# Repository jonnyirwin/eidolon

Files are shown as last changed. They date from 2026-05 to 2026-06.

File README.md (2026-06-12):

> ⚠️ **Work in progress — do not build this yet.** The PCB, case, and firmware have not been validated against a physical build. Things will change, things may be wrong. Watch the commits if you want to follow along, but don't order boards from these files yet.

# Eidolon

> **eidolon** /aɪˈdoʊlɒn/ *noun*
> An idealized image; a phantom or spectre of a person or thing.
> — from Greek εἴδωλον *(image, idol, phantom)*

---

A small column-staggered wireless split keyboard. 30 keys (5×3 + 2 thumb per half), Kailh Choc v1 switches, Seeed XIAO nRF52840 BLE, Totem-style clamshell case. Both halves are independent wireless units — no TRRS cable.

## Built on the shoulders of

| Keyboard | Role in this project |
|---|---|
| [**Phantom**](https://github.com/davidphilipbarr/Phantom) by davidphilipbarr | PCB layout source — key positions reverse-engineered from `lephantom.kicad_pcb`; board outline traced from the original `Edge.Cuts`. Eidolon matches the original key centres to < 0.15 mm. |
| [**TOTEM**](https://github.com/GEIGEIGEIST/TOTEM) by GEIGEIGEIST | Case design reference — switch hole dimensions, keycap recess depth, clamshell geometry, and hot-swap socket pocket profiles all taken from the Totem STEP file. |
| [**Rufous**](https://github.com/jcmkk3/trochilidae/) by jcmkk3 | XIAO BLE footprint and diode placement — `pcb/footprints/xiao_pogo.js` is adapted from the Rufous design; diodes in the Choc south LED cutout follow the same approach. |

## PCB

| Left half | Right half |
|---|---|
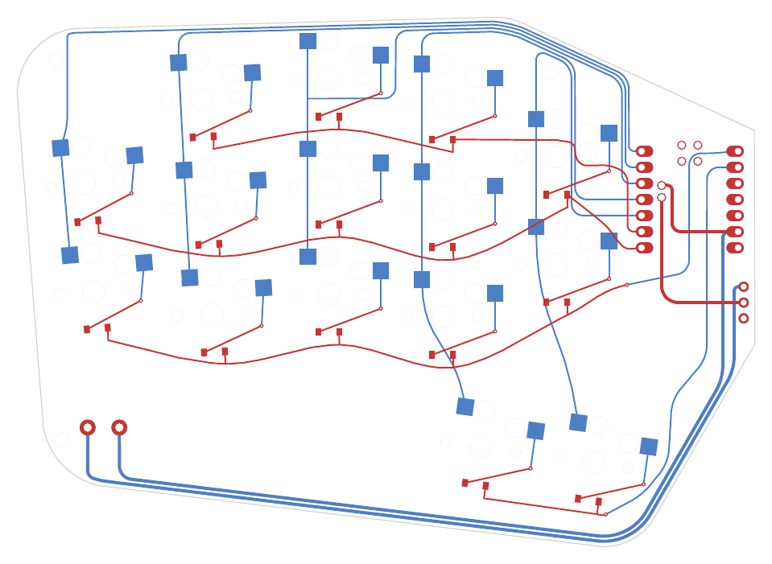
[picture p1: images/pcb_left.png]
Left PCB
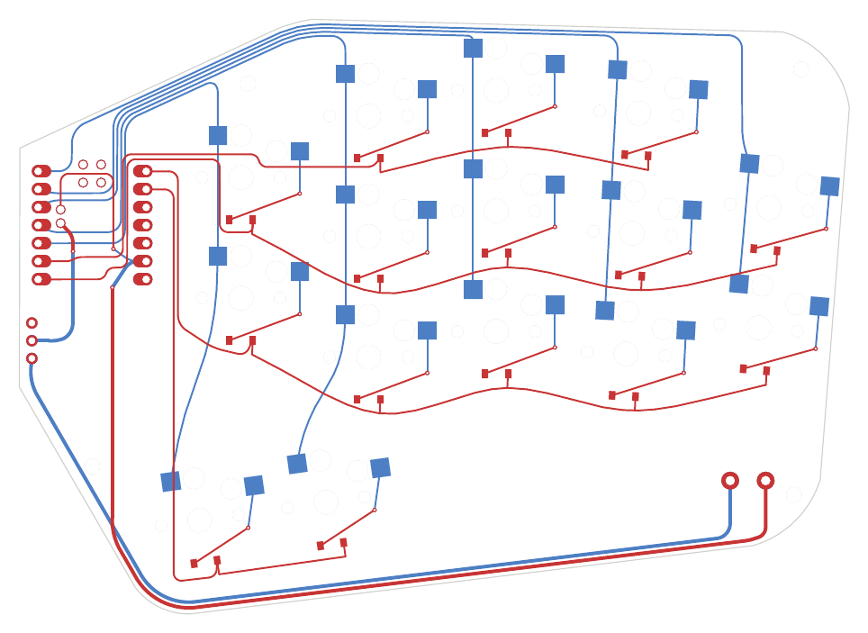
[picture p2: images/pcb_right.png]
Right PCB
|  |  |

## Case

| Top — left | Top — right |
|---|---|
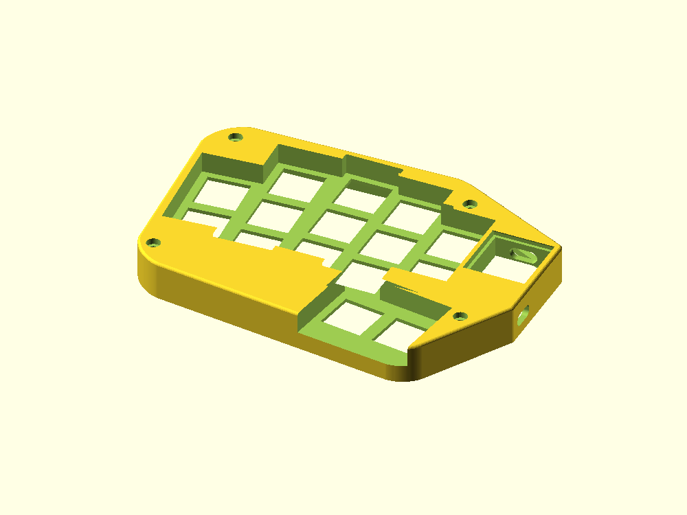
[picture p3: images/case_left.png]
Case top left
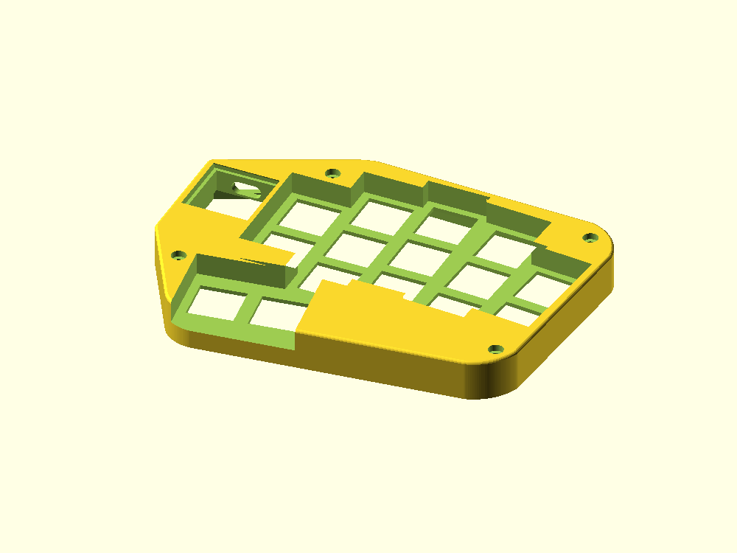
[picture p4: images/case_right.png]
Case top right
|  |  |

| Bottom — left | Bottom — right |
|---|---|
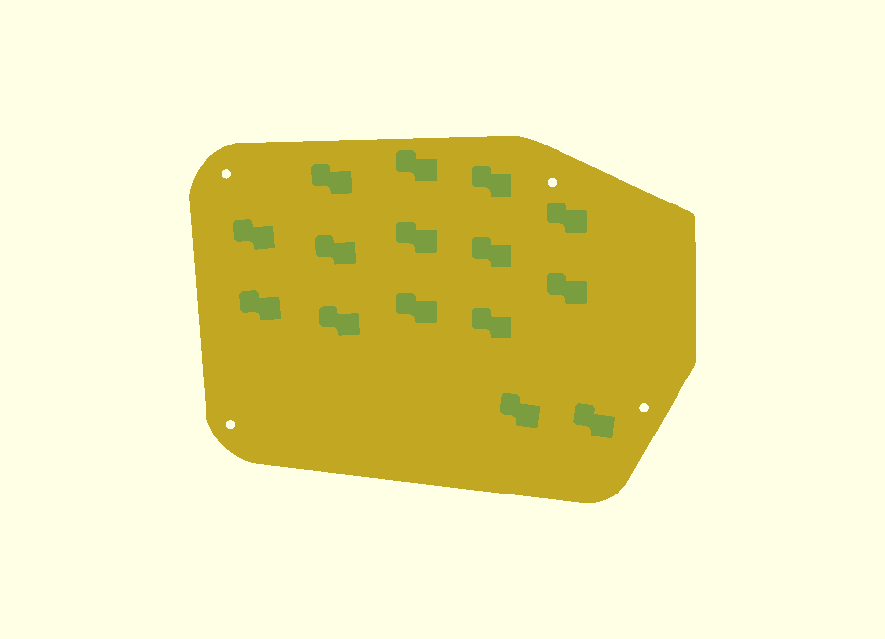
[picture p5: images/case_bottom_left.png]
Case bottom left
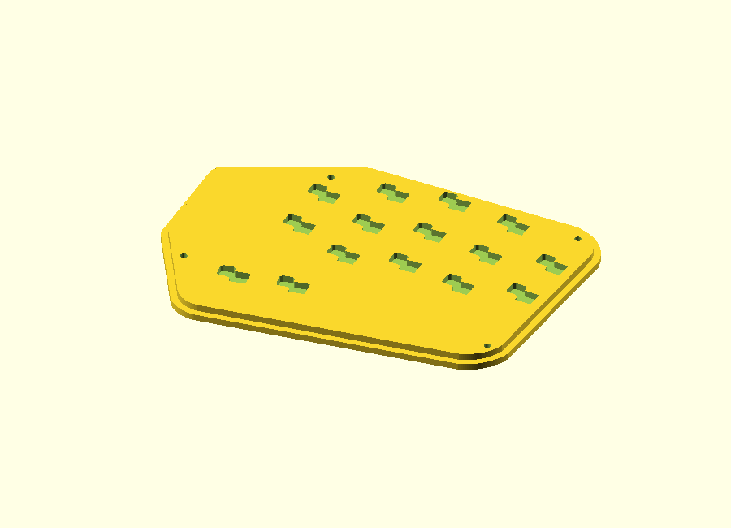
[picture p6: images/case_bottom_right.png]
Case bottom right
|  |  |

---

## Repository layout

```
pcb/              Ergogen source + routed KiCad files + gerbers
  eidolon.yaml      Ergogen config (geometry + nets)
  footprints/       custom Ergogen footprints
  build.js          local build wrapper (injects footprints)
  eidolon_left.kicad_pcb   routed left half
  eidolon_right.kicad_pcb  routed right half
  eidolon_left_gerbers.zip
  eidolon_right_gerbers.zip

case/             OpenSCAD case design
  eidolon_case.scad        top shell (both halves via -D right=true)
  eidolon_case_bottom.scad bottom shell
  stl/                     pre-generated STL files
```

---

## PCB build (Ergogen)

Custom footprints live in `pcb/footprints/`, so use the wrapper rather than the ergogen CLI directly:

```sh
cd pcb
npm install       # once
node build.js     # -> pcb/output/
```

Outputs land in `pcb/output/`:
- `outlines/board_left.svg|dxf`, `board_right.svg|dxf` — board perimeters
- `pcbs/eidolon_left.kicad_pcb`, `eidolon_right.kicad_pcb` — both halves, footprints + nets placed (no routes)

On **ergogen.xyz**, paste each file in `pcb/footprints/` into the web app's Footprints section under its filename (e.g. `reset_button`); `eidolon.yaml` then works as-is.

### Layout

```
 pinky  ring  middle index inner
   ·    top    top   top   ·       (pinky has no top row; inner has no bottom)
 home  home   home  home  upper
 bot   bot    bot   bot   lower
                  thumbL thumbR    (-8°)
```

Pinky splayed 5°, ring splayed 3°; other columns straight. Choc spacing: 18 mm columns, 17 mm rows.

### Wiring — COL2ROW diode matrix (XIAO BLE)

Each half is a fully independent wireless unit (own XIAO + battery, no TRRS).

| Matrix | Net | XIAO pin |
|---|-----|---|
| pinky col | C0 | D0 |
| ring col | C1 | D1 |
| middle col  | C2 | D2 |
| index col | C3 | D3 |
| inner col | C4 | D4 |
| top row | R0 | D5 |
| home row | R1 | D6 |
| bottom row  | R2 | D7 |
| thumb row | R3 | D8 |

Power: battery + → `RAW_BATT` → slide switch → `BATT` → XIAO `B+`; battery − → GND.

> **Verify before fab:** the XIAO pad→pin mapping in `pcb/footprints/xiao_pogo.js` assumes the standard castellation mounted face-down; confirm against the XIAO datasheet.

### Mirrored halves, not reversible

The original Phantom is a single reversible PCB flipped for both hands. Eidolon generates a true left and right board. Functionally identical, but the QMK firmware's `split.matrix_pins.right.direct` should *mirror* the left, not reverse it.

---

## Case (OpenSCAD)

`case/eidolon_case.scad` is the top shell for both halves. The right half is the left mirrored (`-D right=true`).

```sh
openscad -o case/stl/eidolon_case_top_left.stl  case/eidolon_case.scad
openscad -D right=true -o case/stl/eidolon_case_top_right.stl  case/eidolon_case.scad
openscad -o case/stl/eidolon_case_bottom_left.stl  case/eidolon_case_bottom.scad
openscad -D right=true -o case/stl/eidolon_case_bottom_right.stl  case/eidolon_case_bottom.scad
```

Pre-generated STLs are in `case/stl/`.

Top shell features: keycap recess field, stepped 13.8 mm Choc plate holes, XIAO pocket with acrylic window rebate + USB-C cutout, battery pocket, power-switch wall slot, M2 bolt pockets.

### Bottom shell

`case/eidolon_case_bottom.scad` nests inside the top from below. Geometry:

- z ∈ [−0.9, 0]: exterior plate matching the top case outer footprint
- z ∈ [0, 2.1]: nesting lip; PCB rests on the lip top at z = 2.1
- Per-switch hot-swap socket pockets (16 × 7 × 1 mm) cut into the lip top
- M2 hex nut pockets (4.0 mm AF × 1.8 mm) at the four bolt positions

### Mounting hardware

| Part | Spec | Count |
|---|---|---|
| Socket cap bolt | M2 × 12 mm | 4 per half |
| Hex nut | M2 (4.0 mm AF) | 4 per half |

### MCU acrylic window

Cut a piece of 1.5 mm clear acrylic to drop into the XIAO rebate:

| Dimension | Size |
|---|---|
| Width | 20.3 mm |
| Length | 22.8 mm |
| Thickness | 1.5 mm |

Angle the acrylic, slip the +y edge under the square lip (lip A), press the −y edge down past the chamfered lip (lip B). Remove the bottom shell to access the MCU.

---

## Firmware

ZMK firmware for the Eidolon is available at [jonnyirwin/zmk-keyboard-eidolon](https://github.com/jonnyirwin/zmk-keyboard-eidolon).

---

## Deviations from the original Phantom

- **Mirrored L/R** instead of a single reversible board.
- **BLE only** — XIAO nRF52840, COL2ROW diode matrix, battery + slide switch; Pro Micro and TRRS removed.
- **Diodes top-side**, in each Choc south LED gap — hotswap sockets are the only underside component.
- **Trackball omitted.**
- Board outline is the original `Edge.Cuts` polygon with 1.5 mm corner fillets.

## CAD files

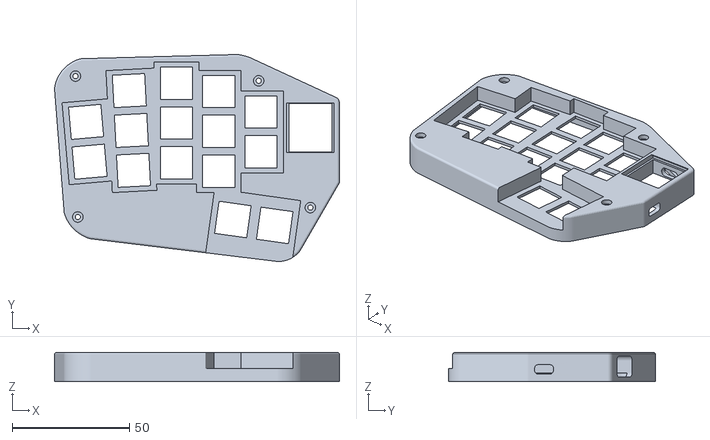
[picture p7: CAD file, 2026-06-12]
case/stl/eidolon_case_top_left.stl
121.3 x 88.1 x 12.5

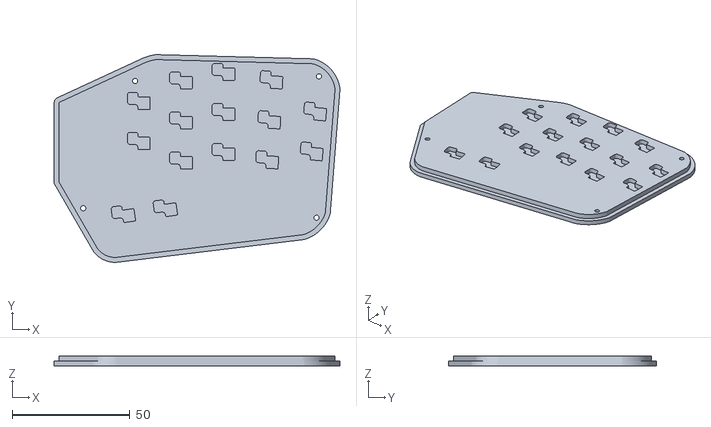
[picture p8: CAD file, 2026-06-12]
case/stl/eidolon_case_bottom_right.stl
121.4 x 88.2 x 4.10

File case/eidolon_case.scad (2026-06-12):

// Eidolon case — BOTH halves (left geometry; right = mirrored build).
// Outline from the PCB Edge.Cuts of lephantom.kicad_pcb (6 lines + 5 arcs,
// exact mm coordinates) plus the two routing reliefs now carried by BOTH
// ergogen PCBs (P1/P2 top edge -0.3mm, P10/P11 pinky edge -0.7mm), so the two
// boards are exact mirror images and one case design fits both. The case
// footprint is the PCB outline grown outward by (gap + wall) so the PCB drops
// inside the walls:
//   gap  = 0.15mm clearance between PCB edge and inner wall
//   wall = 2.0mm  case wall thickness
// then extruded. This pass produces the solid outer shape only.
//
//   openscad -o eidolon_case_top_left.stl  case/eidolon_case.scad
//   openscad -D right=true -o eidolon_case_top_right.stl case/eidolon_case.scad
//
// Right-half fit (verified against the routed ergogen boards): every
// footprint origin mirrors exactly (x_left + x_right = 170, same y), and the
// four case bolts ARE the PCB mounting holes. The XIAO keeps its orientation
// under the PCB mirror, but its position mirrors and the pocket/USB cutout
// are symmetric about the pocket axis, so the mirrored case still fits; the
// power switch flips orientation but its body centre and actuator height are
// unchanged, so the mirrored wall slot lines up.
right = false;   // build the right-half case (mirror of the left)

gap    = 0.15;   // PCB-to-inner-wall clearance (per side)
wall   = 2.0;    // case wall thickness
height = 12.5;   // extrusion depth (mm) — matches Totem top shell
switch = 13.8;   // Choc switch plate cutout (mm square) — Kailh spec / Totem STEP
// Per-column keycap recess. Depth/corner from Totem STEP; opening sized to the
// keycap (not the switch) so caps drop in without catching. At 18mm column pitch
// an 18mm cap leaves no rib, so adjacent column recesses merge into field pockets
// (as on the Totem, whose real recesses are big multi-column pockets).
recess_d = 6.85; // recess depth from top (rim->switch-plate in Totem)
keycap_x = 18.0; // keycap footprint, horizontal
keycap_y = 17.0; // keycap footprint, vertical
key_clr  = 0.5;  // extra clearance per side so caps don't catch
recess_r = 0;  // recess corner fillet
// Widen the recess on the RIGHT of the two leftmost columns (pinky+ring) by
// widen_f, extending them toward the next column to close the inter-column ribs.
// Top switches of the pinky+ring columns (the ones bordering the ribs); the
// bottom switch of each column (9, 11) is left at normal width.
widen_keys = [4, 1, 6];        // pinky-top, ring-top, ring-middle
widen_f    = 0.25;             // +25% width, added entirely on the right
// Stepped switch hole + plate (Totem STEP): below the recess floor sits a thin
// plate carrying the switch. The hole is 13.8mm for plate_t13 then opens to a
// 16mm counterbore for plate_t16; below the plate is a cavity for the PCB.
plate_t13 = 1.2;   // 13.8mm hole depth (upper, switch clips here)
plate_t16 = 0.75;  // 16mm counterbore depth (lower)
cbore     = 16.0;  // counterbore size
// derived z-levels (z=0 bottom, z=height top) — defined here so usb_z0 can use them
plate_top = height - recess_d;                 // recess floor / plate top (5.65)
plate_bot = plate_top - plate_t13 - plate_t16; // plate underside (3.70)
// XIAO BLE microcontroller — walled pocket on the right, a hole straight through
// the case (separate from the keycap recess). At the top (-y) end the slanted
// outer wall is flattened by a rounded-rectangular recess, and the USB-C socket
// cutout pierces that flat into the pocket. The PCB right edge is grown by
// pcb_pad (see outline) so the pocket has board under it + real walls.
xiao_l   = 20.0;            // board length (long axis, vertical / y)
xiao_w   = 17.5;           // board width (x)
xiao_clr = 0.4;            // clearance per side inside the pocket
xiao_pos = [137.0, 44.0];  // pocket center, KiCad coords — up near the top angle
xiao_rot = 0;              // deg; 0 = level with the right edge
// USB-C side: a rounded-rect recess cut into the top-right wall makes a flat
// face usb_wall in front of the pocket; the socket cutout goes through it.
flat_w   = 14.0;           // flat recess width  (x)
flat_h   = 9.0;            // flat recess height (z)
flat_r   = 2.0;            // flat recess corner radius
usb_wall = 2.0;            // wall left between the flat face and the pocket
usb_w    = 9.0;            // USB-C cutout width
usb_h    = 4.0;            // USB-C cutout height (3.2 socket + 0.8 clearance)
// SMD-mounted XIAO (castellated on PCB top): XIAO board sits on plate_bot with
// its own 1.0mm thickness, then the USB-C connector body extends ~3.16mm above
// that. Connector top is at plate_bot + 1.0 + 3.16 = plate_bot + 4.16. Place
// the cutout bottom 0.3mm below the XIAO PCB top to clear the connector body.
usb_z0   = plate_bot + 0.7;
// Acrylic cover over the XIAO through-hole: shallow rebate in the top deck,
// acrylic drops in flush with the deck top and rests on a ledge round the
// pocket. With SMD mount there's no MCU bump, so the rebate sits in the deck.
acrylic_t     = 1.5;       // acrylic thickness
acrylic_ledge = 1.0;       // ledge each side (rebate footprint > pocket footprint)
// Retention lips: deck material above the acrylic on the +/-y short ends that
// overhangs by lip_overhang, capturing the acrylic. One-time install: angle
// the acrylic to slip one short edge under one lip, then bow the acrylic
// slightly to push the other short edge past the second lip.
lip_t       = 0.6;        // lip vertical thickness (~3 print layers at 0.2mm)
lip_overhang= 0.8;        // lip A inward projection (full flat); lip B same width
                          // but flat for lip_b_flat with the rest chamfered.
lip_b_flat  = 0.4;        // lip B's flat retention width at the inner end
                          // (lip_overhang - lip_b_flat = chamfer width)
// Battery pocket — 301230 LiPo cell (3.0 x 12 x 30 mm) sits ON TOP of the PCB
// in the empty palm-rest area, hidden between the PCB and the underside of the
// deck. Pocket is cut UPWARD from plate_bot through the plate into the deck so
// the cell drops in from below before the PCB is seated; wires bend up to F.Cu
// pads on the PCB top (5mm apart, see footprints/battery.js). Bottom of the
// pocket is open to the under-PCB cavity (which the bottom shell will close).
bat_pos    = [59.625, 80.0]; // KiCad — palm-rest area, clear of every keycap pad
bat_rot    = 0;              // long axis along x (-90 = along y)
bat_x      = 38.75;          // pocket: 301230 cell (30) + 0.5 at +x + 8.25 wire
                             // well at -x. The well must hold the pad pair's
                             // 8.5mm copper span (TOTEM 5mm pitch, 2.5mm pads):
                             // moving the pads instead doesn't work — east puts
                             // pad-2 solder under the cell (0.25 margin), west
                             // pokes pad 1 out the wall. -x wall at 40.25 keeps
                             // 0.5 to pad-1 copper and 1.15 to the BL bolt shaft
bat_y      = 14.0;           // pocket width (cell 12 + 1mm each side)
bat_depth  = 3.5;            // cell + 0.5 clearance above plate_bot
// MSK-12D19 power switch — through-hole SPDT on the PCB right edge with the
// actuator overhanging. The case needs a slot in the right wall for the
// actuator/slider; sized for 1.5mm slider travel + clearance.
sw_pos   = [145.5, 60.27]; // switch centre, KiCad — matches ergogen power placement
sw_z     = plate_bot + 1.5;// slot vertical centre = actuator height above the PCB
sw_slot_w = 8.0;           // slot width  (y, along slider travel + cap)
sw_slot_h = 4.0;           // slot height (z)
sw_slot_inward = 5.0;      // how much the slot extends into the case body (-x)
// M2 socket-cap case bolts at 4 corners (KiCad coords). Head sinks into a
// pocket on the deck top; shaft passes through PCB and into a hex-nut pocket
// in the bottom shell. Positions chosen to clear all switches, the MCU pocket,
// the battery pocket, and the power switch slot.
bolts = [
    [ 37,  22],   // TL — inside upper-left arc, above pinky col
    [115,  24],   // TR — above switch 3, clear of MCU pocket
    [ 38,  82],   // BL — left of battery pocket
    [137,  78],   // BR — between thumb 14 pad and right case wall, biased right
];
m2_head_d  = 4.5;  // socket cap head pocket dia (3.8mm head + 0.7 clearance)
m2_head_h  = 2.0;  // head pocket depth = head height -> head top flush w/ deck
m2_shaft_d = 2.2;  // bolt shaft clearance hole
arc_n  = 64;     // points sampled per arc corner
$fn = 128;
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

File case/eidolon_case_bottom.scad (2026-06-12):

// Eidolon case — BOTTOM SHELL.
// Nests inside eidolon_case.scad. Sits below the PCB and pushes it up against
// the top case's plate. Shares outline / switches / bolts / plate_bot with
// the top SCAD via `include` (SUPPRESS_TOP=true skips the top render).
//
//   openscad -o eidolon_case_bottom_left.stl case/eidolon_case_bottom.scad
//
// Geometry (z-up, KiCad y-down — final mirror flips y):
//   z ∈ [-floor_t, 0] : exterior plate, outer = outline + gap + wall, matches
//                       the top case outer so the seam at z=0 is flush.
//   z ∈ [0, lip_h]    : nesting lip, outer = outline + gap - fit_clr, slips
//                       into the top case cavity from below.
//   lip_h = plate_bot - pcb_t = 2.10mm  (PCB underside rest plane).
// Cutouts:
//   - Kailh PG1350 hot-swap socket pockets at each switch — TOTEM silkscreen
//     outline (Z-shape, two bulges). The pockets cut all the way through the
//     lip (z=0 → z=lip_h) so a 1.8mm-tall socket fits, but the exterior
//     plate seals them at the bottom, so the sockets are not visible from
//     outside. Socket bottom ends ~0.3mm above the floor top.
//   - M2 hex-nut pockets in the bottom face at the four corner bolts.
//   - M2 shaft holes through the whole shell.

SUPPRESS_TOP = true;
include <eidolon_case.scad>;

// === bottom-shell dimensions ===
pcb_t           = 1.6;                 // PCB thickness
floor_t         = 2.0;                 // exterior plate below z=0 (2mm min wall)
lip_h           = plate_bot - pcb_t;   // 2.10mm — nesting lip top = PCB underside
fit_clr         = 0.1;                 // lip-to-top-case-cavity slip clearance

// Kailh PG1350 hot-swap socket body outline in switch local frame, traced from
// TOTEM's Kailh_socket_PG1350_optional.kicad_mod silkscreen — a Z-shape with
// two rectangular bulges (one around each SMD pad) connected by curves. Pads
// are at (-3.275, -5.95) and (8.275, -3.75). The polygon hugs the body; a
// small inflation by socket_clr is applied at use to give plastic clearance.
socket_outline = [
    [-2.0,    -4.2  ], [-2.0,    -7.7  ],
    [-1.5,    -8.2  ], [ 1.5,    -8.2  ],
    [ 2.0,    -7.7  ], [ 2.0,    -6.7  ],
    [ 2.1464, -6.3464],                     // arc midpoint (lower inner corner)
    [ 2.5,    -6.2  ], [ 7.0,    -6.2  ],
    [ 7.0,    -1.5  ], [ 2.5,    -1.5  ],
    [ 2.5,    -2.2  ],
    [ 2.0607, -3.2607],                     // arc midpoint (upper inner corner)
    [ 1.0,    -3.7  ], [-1.5,    -3.7  ]
];
socket_clr = 0.3;  // inflate the outline by this much for socket plastic slop

// M2 hex nut: 4.0mm across flats. Hex circumradius = 4/√3 ≈ 2.31, plus slack.
m2_nut_af = 4.0;
m2_nut_h  = 1.8;   // nut thickness; pocket depth from the bottom face upward

module bottom_body()
    union() {
        translate([0, 0, -floor_t])
            linear_extrude(floor_t)
                offset(r = gap + wall) polygon(outline);
        linear_extrude(lip_h)
            offset(r = gap - fit_clr) polygon(outline);
    }

// Hot-swap socket pockets — through-cut the full lip height so a 1.8mm-tall
// socket fits. The exterior floor seals the cuts from outside; the socket
// bottom ends ~0.3mm above the floor top (z=0). Rotated per switch.
// The hotswap sockets do NOT mirror on the right-half PCB (they keep their
// orientation; verified: right S3 drill at centre +5, pad 2 at centre +8.275,
// same as left). The Z-shaped pocket is chiral, so for the right build the
// polygon is mirrored LOCALLY — the global mirror([1,0,0]) then cancels it,
// leaving the pocket in the same chirality as the physical socket.
module socket_pockets()
    for (s = switches)
        translate([s[0], s[1], 0])
            rotate([0, 0, -s[2]])
                linear_extrude(lip_h + 0.01)
                    if (right)
                        mirror([1, 0])
                            offset(r = socket_clr) polygon(socket_outline);
                    else
                        offset(r = socket_clr) polygon(socket_outline);

// Hex nut pockets in the bottom face (z = -floor_t), m2_nut_h deep upward.
module nut_pockets()
    for (b = bolts)
        translate([b[0], b[1], -floor_t - 0.01])
            linear_extrude(m2_nut_h + 0.01)
                circle(r = m2_nut_af / sqrt(3) + 0.07, $fn = 6);

// Bolt shaft holes — all the way through so the bolt can engage the nut.
module bolt_shafts()
    for (b = bolts)
        translate([b[0], b[1], -floor_t - 1])
            linear_extrude(lip_h + floor_t + 2)
                circle(d = m2_shaft_d, $fn = 96);

module bottom_case()
    mirror([0, 1, 0])
        difference() {
            bottom_body();
            socket_pockets();
            nut_pockets();
            bolt_shafts();
        }

// Preview: render top + bottom together for fit check. EXPLODED > 0 lifts the
// top by that many mm; 0 = fully assembled. `right` (from the included top
// SCAD, or -D right=true) mirrors the build for the right half:
//   openscad -D right=true -o eidolon_case_bottom_right.stl case/eidolon_case_bottom.scad
PREVIEW  = false;
EXPLODED = 6;

module bottom_build() {
    if (PREVIEW) {
        bottom_case();
        translate([0, 0, EXPLODED]) top_case();
    } else {
        bottom_case();
    }
}

if (right) mirror([1, 0, 0]) bottom_build();
else bottom_build();

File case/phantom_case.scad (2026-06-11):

// Phantom case — BOTH halves (left geometry; right = mirrored build).
// Outline from the PCB Edge.Cuts of lephantom.kicad_pcb (6 lines + 5 arcs,
// exact mm coordinates) plus the two routing reliefs now carried by BOTH
// ergogen PCBs (P1/P2 top edge -0.3mm, P10/P11 pinky edge -0.7mm), so the two
// boards are exact mirror images and one case design fits both. The case
// footprint is the PCB outline grown outward by (gap + wall) so the PCB drops
// inside the walls:
//   gap  = 0.15mm clearance between PCB edge and inner wall
//   wall = 2.0mm  case wall thickness
// then extruded. This pass produces the solid outer shape only.
//
//   openscad -o phantom_case_left.stl  case/phantom_case.scad
//   openscad -D right=true -o phantom_case_right.stl case/phantom_case.scad
//
// Right-half fit (verified against the routed ergogen boards): every
// footprint origin mirrors exactly (x_left + x_right = 170, same y), and the
// four case bolts ARE the PCB mounting holes. The XIAO keeps its orientation
// under the PCB mirror, but its position mirrors and the pocket/USB cutout
// are symmetric about the pocket axis, so the mirrored case still fits; the
// power switch flips orientation but its body centre and actuator height are
// unchanged, so the mirrored wall slot lines up.
right = false;   // build the right-half case (mirror of the left)

gap    = 0.15;   // PCB-to-inner-wall clearance (per side)
wall   = 2.0;    // case wall thickness
height = 12.5;   // extrusion depth (mm) — matches Totem top shell
switch = 13.8;   // Choc switch plate cutout (mm square) — Kailh spec / Totem STEP
// Per-column keycap recess. Depth/corner from Totem STEP; opening sized to the
// keycap (not the switch) so caps drop in without catching. At 18mm column pitch
// an 18mm cap leaves no rib, so adjacent column recesses merge into field pockets
// (as on the Totem, whose real recesses are big multi-column pockets).
recess_d = 6.85; // recess depth from top (rim->switch-plate in Totem)
keycap_x = 18.0; // keycap footprint, horizontal
keycap_y = 17.0; // keycap footprint, vertical
key_clr  = 0.5;  // extra clearance per side so caps don't catch
recess_r = 0;  // recess corner fillet
// Widen the recess on the RIGHT of the two leftmost columns (pinky+ring) by
// widen_f, extending them toward the next column to close the inter-column ribs.
// Top switches of the pinky+ring columns (the ones bordering the ribs); the
// bottom switch of each column (9, 11) is left at normal width.
widen_keys = [4, 1, 6];        // pinky-top, ring-top, ring-middle
widen_f    = 0.25;             // +25% width, added entirely on the right
// Stepped switch hole + plate (Totem STEP): below the recess floor sits a thin
// plate carrying the switch. The hole is 13.8mm for plate_t13 then opens to a
// 16mm counterbore for plate_t16; below the plate is a cavity for the PCB.
plate_t13 = 1.2;   // 13.8mm hole depth (upper, switch clips here)
plate_t16 = 0.75;  // 16mm counterbore depth (lower)
cbore     = 16.0;  // counterbore size
// derived z-levels (z=0 bottom, z=height top) — defined here so usb_z0 can use them
plate_top = height - recess_d;                 // recess floor / plate top (5.65)
plate_bot = plate_top - plate_t13 - plate_t16; // plate underside (3.70)
// XIAO BLE microcontroller — walled pocket on the right, a hole straight through
// the case (separate from the keycap recess). At the top (-y) end the slanted
// outer wall is flattened by a rounded-rectangular recess, and the USB-C socket
// cutout pierces that flat into the pocket. The PCB right edge is grown by
// pcb_pad (see outline) so the pocket has board under it + real walls.
xiao_l   = 20.0;            // board length (long axis, vertical / y)
xiao_w   = 17.5;           // board width (x)
xiao_clr = 0.4;            // clearance per side inside the pocket
xiao_pos = [137.0, 44.0];  // pocket center, KiCad coords — up near the top angle
xiao_rot = 0;              // deg; 0 = level with the right edge
// USB-C side: a rounded-rect recess cut into the top-right wall makes a flat
// face usb_wall in front of the pocket; the socket cutout goes through it.
flat_w   = 14.0;           // flat recess width  (x)
flat_h   = 9.0;            // flat recess height (z)
flat_r   = 2.0;            // flat recess corner radius
usb_wall = 2.0;            // wall left between the flat face and the pocket
usb_w    = 9.0;            // USB-C cutout width
usb_h    = 4.0;            // USB-C cutout height (3.2 socket + 0.8 clearance)
// SMD-mounted XIAO (castellated on PCB top): XIAO board sits on plate_bot with
// its own 1.0mm thickness, then the USB-C connector body extends ~3.16mm above
// that. Connector top is at plate_bot + 1.0 + 3.16 = plate_bot + 4.16. Place
// the cutout bottom 0.3mm below the XIAO PCB top to clear the connector body.
usb_z0   = plate_bot + 0.7;
// Acrylic cover over the XIAO through-hole: shallow rebate in the top deck,
// acrylic drops in flush with the deck top and rests on a ledge round the
// pocket. With SMD mount there's no MCU bump, so the rebate sits in the deck.
acrylic_t     = 1.5;       // acrylic thickness
acrylic_ledge = 1.0;       // ledge each side (rebate footprint > pocket footprint)
// Retention lips: deck material above the acrylic on the +/-y short ends that
// overhangs by lip_overhang, capturing the acrylic. One-time install: angle
// the acrylic to slip one short edge under one lip, then bow the acrylic
// slightly to push the other short edge past the second lip.
lip_t       = 0.6;        // lip vertical thickness (~3 print layers at 0.2mm)
lip_overhang= 0.8;        // lip A inward projection (full flat); lip B same width
                          // but flat for lip_b_flat with the rest chamfered.
lip_b_flat  = 0.4;        // lip B's flat retention width at the inner end
                          // (lip_overhang - lip_b_flat = chamfer width)
// Battery pocket — 301230 LiPo cell (3.0 x 12 x 30 mm) sits ON TOP of the PCB
// in the empty palm-rest area, hidden between the PCB and the underside of the
// deck. Pocket is cut UPWARD from plate_bot through the plate into the deck so
// the cell drops in from below before the PCB is seated; wires bend up to F.Cu
// pads on the PCB top (5mm apart, see footprints/battery.js). Bottom of the
// pocket is open to the under-PCB cavity (which the bottom shell will close).
bat_pos    = [59.625, 80.0]; // KiCad — palm-rest area, clear of every keycap pad
bat_rot    = 0;              // long axis along x (-90 = along y)
bat_x      = 38.75;          // pocket: 301230 cell (30) + 0.5 at +x + 8.25 wire
                             // well at -x. The well must hold the pad pair's
                             // 8.5mm copper span (TOTEM 5mm pitch, 2.5mm pads):
                             // moving the pads instead doesn't work — east puts
                             // pad-2 solder under the cell (0.25 margin), west
                             // pokes pad 1 out the wall. -x wall at 40.25 keeps
                             // 0.5 to pad-1 copper and 1.15 to the BL bolt shaft
bat_y      = 14.0;           // pocket width (cell 12 + 1mm each side)
bat_depth  = 3.5;            // cell + 0.5 clearance above plate_bot
// MSK-12D19 power switch — through-hole SPDT on the PCB right edge with the
// actuator overhanging. The case needs a slot in the right wall for the
// actuator/slider; sized for 1.5mm slider travel + clearance.
sw_pos   = [145.5, 60.27]; // switch centre, KiCad — matches ergogen power placement
sw_z     = plate_bot + 1.5;// slot vertical centre = actuator height above the PCB
sw_slot_w = 8.0;           // slot width  (y, along slider travel + cap)
sw_slot_h = 4.0;           // slot height (z)
sw_slot_inward = 5.0;      // how much the slot extends into the case body (-x)
// M2 socket-cap case bolts at 4 corners (KiCad coords). Head sinks into a
// pocket on the deck top; shaft passes through PCB and into a hex-nut pocket
// in the bottom shell. Positions chosen to clear all switches, the MCU pocket,
// the battery pocket, and the power switch slot.
bolts = [
    [ 37,  22],   // TL — inside upper-left arc, above pinky col
    [115,  24],   // TR — above switch 3, clear of MCU pocket
    [ 38,  82],   // BL — left of battery pocket
    [137,  78],   // BR — between thumb 14 pad and right case wall, biased right
];
m2_head_d  = 4.5;  // socket cap head pocket dia (3.8mm head + 0.7 clearance)
m2_head_h  = 2.0;  // head pocket depth = head height -> head top flush w/ deck
m2_shaft_d = 2.2;  // bolt shaft clearance hole
arc_n  = 64;     // points sampled per arc corner
$fn = 128;
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

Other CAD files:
case/stl/eidolon_case_top_right.stl
case/stl/eidolon_case_bottom_left.stl
case/phantom_case_bottom.scad

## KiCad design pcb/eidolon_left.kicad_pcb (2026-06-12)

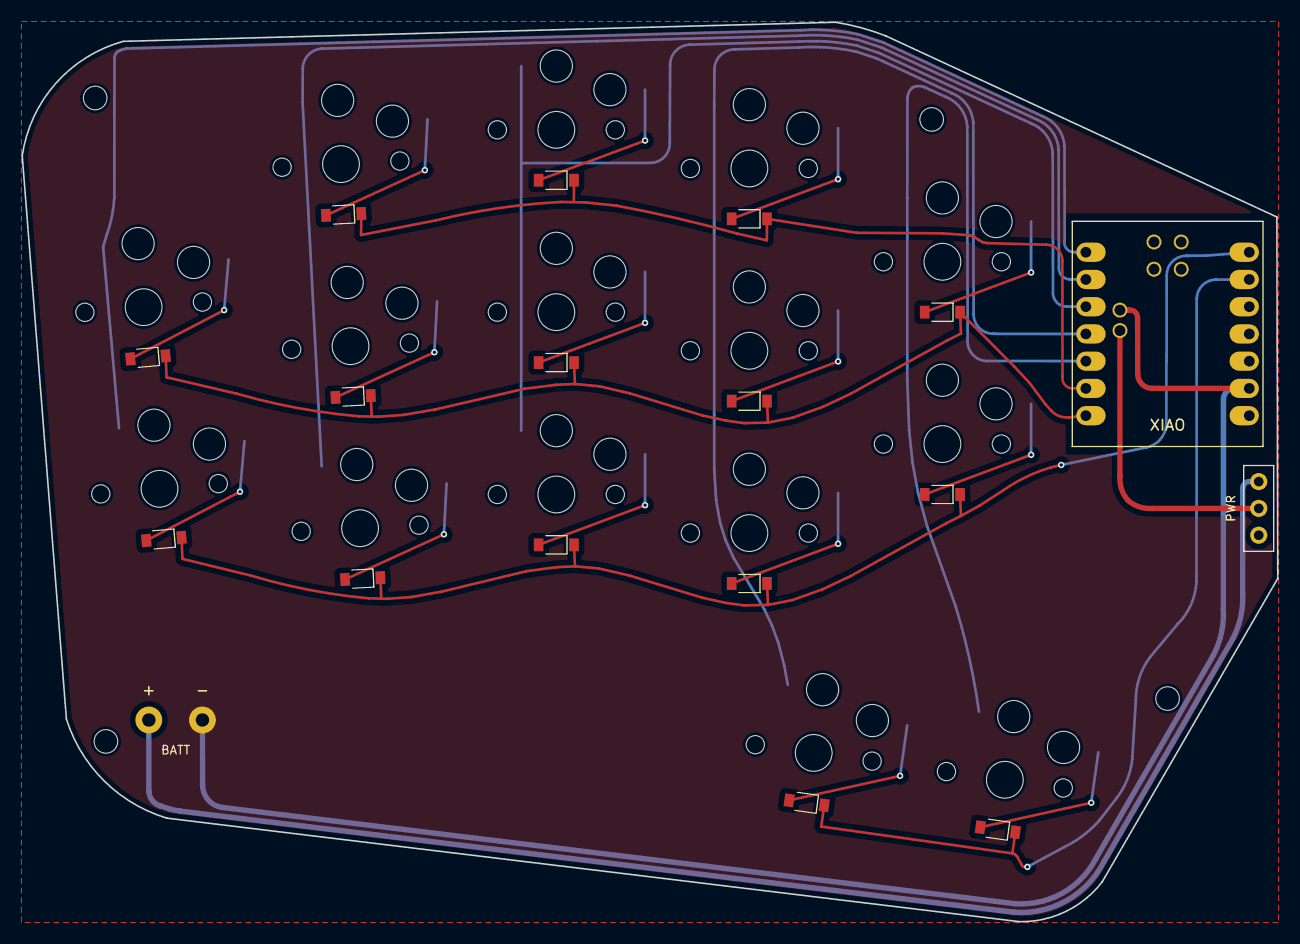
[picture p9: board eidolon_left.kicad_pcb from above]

Board: 2 copper layers, 117.1 x 83.9 mm, 37 parts (0 on the bottom side), 27 nets.

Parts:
BT1: battery_pads
D1, D2, D3, D4, D5, D6, D7, D8, D9, D10, D11, D12, D13, D14, D15: diode_sod123
MCU1: xiao_ble
MH1, MH2, MH3, MH4: mounting_hole_m2
S1, S2, S3, S4, S5, S6, S7, S8, S9, S10, S11, S12, S13, S14, S15: PG1350
SW1: power_switch_spdt

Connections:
BATT: MCU1.BAT, SW1.2
C0: MCU1.1, S12.1, S13.1
C1: MCU1.2, S9.1, S10.1, S11.1
C2: MCU1.3, S1.1, S2.1, S3.1
C3: MCU1.4, S4.1, S5.1, S6.1, S14.1
C4: MCU1.5, S7.1, S8.1, S15.1
GND: BT1.2, MCU1.9, MCU1.GND
R0: D3.2, D6.2, D11.2, MCU1.6
R1: D2.2, D5.2, D8.2, D10.2, D13.2, MCU1.7
R2: D1.2, D4.2, D7.2, D9.2, D12.2, MCU1.14
R3: D14.2, D15.2, MCU1.13
RAW_BATT: BT1.1, SW1.1
matrix_index_bottom: D4.1, S4.2
matrix_index_home: D5.1, S5.2
matrix_index_top: D6.1, S6.2
matrix_inner_bottom: D7.1, S7.2
matrix_inner_home: D8.1, S8.2
matrix_middle_bottom: D1.1, S1.2
matrix_middle_home: D2.1, S2.2
matrix_middle_top: D3.1, S3.2
pinky_pinky_bottom: D12.1, S12.2
pinky_pinky_home: D13.1, S13.2
ring_ring_bottom: D9.1, S9.2
ring_ring_home: D10.1, S10.2
ring_ring_top: D11.1, S11.2
thumb_left_thumb: D14.1, S14.2
thumb_right_thumb: D15.1, S15.2

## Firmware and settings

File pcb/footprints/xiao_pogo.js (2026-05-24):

// Seeed XIAO (nRF52840 BLE) on pogo pins, mounted face-down over the PCB.
// Geometry adapted from jcmkk3/trochilidae `XiaoSimplePogo.kicad_mod`:
// 14 thru-hole pogo landing pads in two columns (2.54mm pitch, 15.33mm apart)
// plus a B+ battery pad. Footprint is ~17.8 x 21 mm; USB faces the +y (top) edge.
//
// Pad->pin mapping assumes the standard XIAO castellation mounted FACE-DOWN
// (USB toward +y). VERIFY against the XIAO datasheet before ordering; the user
// adapts firmware to whatever GPIO the matrix is wired to here.
//   left col  (x 1.25, top->bottom):  5V  GND 3V3 D10 D9 D8 D7
//   right col (x16.58, top->bottom):  D0  D1  D2  D3  D4 D5 D6
module.exports = {
  params: {
    designator: 'MCU',
    side: 'F',
    P5V: { type: 'net', value: 'P5V' },
    GND: { type: 'net', value: 'GND' },
    P3V3: { type: 'net', value: 'P3V3' },
    BAT: { type: 'net', value: 'BAT' },
    D0: { type: 'net', value: 'D0' }, D1: { type: 'net', value: 'D1' },
    D2: { type: 'net', value: 'D2' }, D3: { type: 'net', value: 'D3' },
    D4: { type: 'net', value: 'D4' }, D5: { type: 'net', value: 'D5' },
    D6: { type: 'net', value: 'D6' }, D7: { type: 'net', value: 'D7' },
    D8: { type: 'net', value: 'D8' }, D9: { type: 'net', value: 'D9' },
    D10: { type: 'net', value: 'D10' }
  },
  body: p => {
    // pad helper: thru-hole pogo landing
    const pad = (name, x, y, net) =>
      `(pad "${name}" thru_hole circle (at ${x} ${y} ${p.r}) (size 1.524 1.524) (drill 1) (layers *.Cu *.Mask) ${net})`
    return `
    (module xiao_pogo (layer F.Cu) (tstamp 0)
      (descr "Seeed XIAO on pogo pins (face-down), adapted from trochilidae XiaoSimplePogo")
      (tags "xiao nrf52840 ble pogo")
      ${p.at}
      (fp_text reference "${p.ref}" (at 8.9 -10.5) (layer ${p.side}.SilkS) ${p.ref_hide} (effects (font (size 1 1) (thickness 0.15))))
      (fp_text value "" (at 0 0) (layer ${p.side}.SilkS) hide (effects (font (size 1 1) (thickness 0.15))))
      (fp_text user "XIAO" (at 8.9 -8 ${p.r}) (layer ${p.side}.SilkS) (effects (font (size 1 1) (thickness 0.15))))
      (fp_text user "USB" (at 8.9 -20 ${p.r}) (layer ${p.side}.SilkS) (effects (font (size 0.8 0.8) (thickness 0.12))))
      ${'' /* body outline ~17.8 x 21 mm */}
      (fp_line (start 0 0) (end 17.8 0) (layer ${p.side}.SilkS) (width 0.12))
      (fp_line (start 0 -21) (end 17.8 -21) (layer ${p.side}.SilkS) (width 0.12))
      (fp_line (start 0 0) (end 0 -21) (layer ${p.side}.SilkS) (width 0.12))
      (fp_line (start 17.8 0) (end 17.8 -21) (layer ${p.side}.SilkS) (width 0.12))
      ${'' /* left column: 5V GND 3V3 D10 D9 D8 D7 (top->bottom) */}
      ${pad('5V',  1.25, -18.11782, p.P5V)}
      ${pad('GND', 1.25, -15.57782, p.GND)}
      ${pad('3V3', 1.25, -13.03782, p.P3V3)}
      ${pad('D10', 1.25, -10.49782, p.D10)}
      ${pad('D9',  1.25,  -7.95782, p.D9)}
      ${pad('D8',  1.25,  -5.41782, p.D8)}
      ${pad('D7',  1.25,  -2.87782, p.D7)}
      ${'' /* right column: D6 D5 D4 D3 D2 D1 D0 (bottom->top) */}
      ${pad('D6',  16.581, -2.87782, p.D6)}
      ${pad('D5',  16.581, -5.41782, p.D5)}
      ${pad('D4',  16.581, -7.95782, p.D4)}
      ${pad('D3',  16.581, -10.49782, p.D3)}
      ${pad('D2',  16.581, -13.03782, p.D2)}
      ${pad('D1',  16.581, -15.57782, p.D1)}
      ${pad('D0',  16.581, -18.11782, p.D0)}
      ${'' /* battery + landing (XIAO underside BAT+) */}
      (pad "B+" thru_hole oval (at 4.4705 -10.93409 ${p.r}) (size 1.5 1) (drill 0.508) (layers *.Cu *.Mask) ${p.BAT})
      ${'' /* copper-pour keepout under the whole XIAO so a ground plane never
            reaches the nRF52840 antenna (BLE detuning). From XiaoSimplePogo. */}
      (zone (net 0) (net_name "") (layers F&B.Cu) (hatch edge 0.508)
        (connect_pads (clearance 0)) (min_thickness 0.254)
        (keepout (tracks allowed) (vias allowed) (pads allowed) (copperpour not_allowed) (footprints allowed))
        (fill (thermal_gap 0.508) (thermal_bridge_width 0.508))
        (polygon (pts (xy 0 0) (xy 17.8 0) (xy 17.8 -21) (xy 0 -21))))
    )
    `
  }
}

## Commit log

2026-05-23 Baseline: faithful Ergogen recreation of the Phantom
    Reverse-engineered from lephantom.kicad_pcb (geometry, <0.15mm match) and
    phantom_qmk_config (DIRECT_PINS wiring). Pro Micro + TRRS split, hotswap Choc,
    no diode matrix, trackball omitted.
    - exact board outline traced from the original Edge.Cuts polygon
    - mirrored L/R: emits phantom_left + phantom_right (two PCBs, two outlines)
2026-05-24 feat: XIAO nRF52840 BLE + battery + side power switch, diode matrix
    Replace the Pro Micro + TRRS (direct pins) with a wireless setup per half:
    - COL2ROW diode matrix (cols C0-C4, rows R0-R3) -> XIAO D0-D8
    - pogo-pin XIAO footprint adapted from jcmkk3/trochilidae XiaoSimplePogo
    - LiPo battery pads + 3-pin slide power switch (battery+ -> switch -> XIAO B+)
    - drop TRRS and the dedicated reset (XIAO uses double-tap reset)
    All footprints verified inside the edge on both mirrored halves.
    XIAO pad->pin mapping is the standard face-down castellation; verify before fab.
    [xiao_pogo.js]
2026-05-24 feat: Totem-style 3D-printed case (left half)
    Parametric OpenSCAD clamshell that imports the Ergogen outline DXFs:
    - bottom tray: PCB flush, hotswap-socket pockets in the floor, USB cutout (top)
    and power-switch slot (right edge), perimeter walls
    - top switch-plate: 14mm Choc cutouts
    - two new Ergogen outlines feed it: plate_left, socketpockets_left
    Preview/STL via openscad. Join method, battery pocket, USB-Z (pogo height) and
    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
    [case_left.scad]
2026-05-26 feat: case from PCB Edge.Cuts — outer shell (left)
    Replace the Totem-style case with a new approach: the LEFT-half case
    outline reconstructed directly from lephantom.kicad_pcb Edge.Cuts (6 lines
    + 5 arcs, exact mm coords; arcs rebuilt through their start/mid/end).
    Outline grown outward by gap+wall (0.15 + 2.0 = 2.15mm) so the PCB seats
    inside the walls, then extruded to 16mm. Solid outer shape only for now.
    [case_left.scad, phantom_case.scad]
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2026-05-26 feat: set case height to 12.5mm to match Totem top shell
    [phantom_case.scad]
2026-05-26 feat: add 13.8mm Choc switch cutouts (left)
    15 switch cutouts at the exact SW_PG1350 positions from lephantom.kicad_pcb
    (18mm column / 17mm row pitch, column splay + thumb angle). Sized 13.8mm to
    match the Kailh Choc plate spec and the Totem STEP. Rotation negated to undo
    the mirror's flip of rotation sense, so each cutout aligns to its column splay.
    [phantom_case.scad]
2026-05-26 pre-jonny changes
    [phantom_case.scad]
2026-05-27 feat: keycap recess, stepped switch holes + plate (left)
    Replace the through-cuts with the full Totem vertical stack (measured from
    the STEP) in the 12.5mm height:
    - single open keycap recess (no ribs), union of 18x17 + 0.5mm-clearance pads,
    6.85mm deep
    - stepped switch hole: 13.8mm (1.2mm) opening to a 16mm counterbore (0.75mm)
    - ~2mm switch plate at z 3.70-5.65, with an open-bottom PCB cavity below
    (board outline + gap), making this a top shell
    [phantom_case.scad]
2026-05-27 feat: widen pinky/ring top recesses to close inter-column ribs (left)
    Widen the recess 25% on the right for the top switches of the pinky and ring
    columns (indices 4, 1, 6), extending them into the next column to close the
    pinky->ring and ring->middle ribs. Bottom switches (9, 11) stay normal width;
    their rows already overlap, so no rib reappears.
    [phantom_case.scad]
2026-05-27 feat: extend thumb recess to right/bottom edges, no rim wall there (left)
    Keep the thumb recess's angled-rectangle shape but run its right and bottom
    edges out past the case so (clipped by the body) they meet the outer edge,
    leaving no rim wall on the thumbs' right and bottom. Anchored at the left thumb
    key's top-left so top/left edges stay put. Thumb pocket remains separate from
    the main field.
    [phantom_case.scad]
2026-05-27 feat: extend thumb recess up to join the 4th-column corner (left)
    Grow the thumb recess top edge straight up along its own 8-degree axis (angles
    unchanged) until it reaches the 4th-column bottom-right corner, joining the
    thumb and main-field recesses. Right/bottom edges still run to the case edge.
    [phantom_case.scad]
2026-05-28 feat: XIAO pocket + USB-C side recess; resize and smooth top-right corner
    Case (case/phantom_case.scad):
    - XIAO pocket: full-height through-hole on the right (20 x 17.5mm + 0.4mm
    clearance), placed at KiCad (137, 44) so its USB end sits just inside the
    upper-right wall.
    - USB-C side recess: rounded-rectangular pocket cut into the top-right wall
    to create a flat face 2mm in front of the XIAO; the USB-C cutout pierces
    that flat into the pocket.
    - Right edge enlarged by pcb_pad=3mm so the XIAO has board under it + real
    walls (~2mm) on both sides.
    - Upper-right corner: source PCB had a ~7 deg kink at the diagonal/arc
    junction and a ~1.56 deg kink at the top-edge junction. Replaced wi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
    [phantom_case.scad]
2026-05-28 feat: XIAO acrylic rebate + MSK-12D19 power switch in case wall
    - Acrylic rebate on top of XIAO pocket: 3mm-deep flush recess sized to
    the pocket + 1mm ledge per side, so a 3mm acrylic square drops in flush
    over the XIAO through-hole and rests on the deck ledge.
    - Power switch wall slot: 8 x 4mm rectangular hole through the right
    wall at the MSK-12D19 actuator height (plate_bot + 1.5mm), extended
    sw_slot_inward (5mm) into the case body so the switch body has room
    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
    [phantom_case.scad]
2026-05-28 feat: 45 degree chamfer on the top outside edge of the case
    case/phantom_case.scad:
    - New body_chamfered() module: straight wall extruded from z=0 to
    height-chamfer, then a hull cap that insets the outline by chamfer
    (default 1mm) over the top chamfer of z, giving a clean 45 deg bevel
    on the entire top outside edge.
    - chamfer parameter (default 1.0mm) added next to gap/wall/height.
    [phantom_case.scad]
2026-05-28 reduce acrylic cover depth to 1.5mm
    [phantom_case.scad]
2026-06-07 feat: switch XIAO to castellated SMT mount + add battery pocket
    - New footprints/xiao_ble.js: TOTEM-style castellated half-hole mount with
    underside BAT/RST access thru-holes. Replaces the pogo-pin variant.
    - battery.js: pads bumped to TOTEM geometry (2.5mm dia, 1.25 drill, 5mm pitch).
    - config.yaml: wire MCU to xiao_ble; relocate battery to the palm-rest area
    at one end of the new SCAD battery pocket so cell wires don't loop back;
    centre diodes on the Choc south LED notch (-5.95 from switch centre).
    - SCAD: drop the mcu_rise pillar (no longer needed with SMD-mounted XIAO);
    lower the USB-C cutout to match XIAO PCB+connector height; add a 38x14mm
    battery pocket carved up from plate_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
    [phantom_case.scad]
2026-06-07 feat: rounded USB/power cutouts, top-edge fillet, battery pocket fixes
    - USB-C cutout: stadium shape (9x4, 2mm semicircular ends) to match the
    real connector and any plug shroud.
    - Power switch slot: 8x4 rounded-rect (1.5mm corner radius) for cleaner
    print and easier slider entry.
    - Top outside edge: 1mm fillet via minkowski with an upper-hemisphere
    kernel; pre-compensated so total height and footprint are preserved.
    - Battery pocket: shifted south to clear the ring-bottom keycap pad,
    extruded slightly below plate_bot so the cutout reads clearly in F5.
    - Config battery shift updated to keep pads at the pocket's wire-well end.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
    [phantom_case.scad]
2026-06-08 feat: bottom shell + M2 case-to-case mounting hardware
    - New case/phantom_case_bottom.scad: nests inside the top case via shared
    outline / switches / bolts (include with SUPPRESS_TOP). Has an exterior
    2mm plate (full footprint) and a 2.1mm lip that slips into the top case
    cavity. PCB rests on the lip top.
    - TOTEM-shaped hot-swap socket pockets cut through the full lip height so
    the 1.8mm socket body fits; the exterior plate seals them from outside.
    Per-switch rotation applied so thumb (-8 deg) sockets land correctly.
    - M2 nut pockets (hex, 4mm AF x 1.8mm) in the bottom face at the four
    corners; bolt shaft holes (2.2mm) through. M2 head pockets sized for
    flush mount (2mm deep).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
    [phantom_case.scad, phantom_case_bottom.scad]
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2026-06-08 feat(router): route diode rows on F.Cu (autorouter step 7)
    Generalise route_columns into route_spine(board, klass, footprints): columns
    and rows are the same problem on layers read per-net from the pads. Columns
    thread PG1350 switch pads (B.Cu), rows thread diode_sod123 pads (F.Cu); the
    MCU pad on each matrix net is deferred to fan-out as before.
    154 tracks total (73 column + 81 row), reloads cleanly in pcbnew. Verified
    per-row that PCA ordering matches sort-by-X and the spine stays within the
    pads' Y-extent (no axis flip, overshoot, or fold-back).
2026-06-08 feat(router): per-key matrix-link vias (autorouter step 8)
    Add a kwrite.via() emitter and route_matrix_links(): each of the 15 matrix_*
    nets is one switch pad (B.Cu) + one diode pad (F.Cu); anchor a 0.6/0.3 via on
    the diode pad (rotation-correct via the footprint, no special thumb handling)
    with a B.Cu stub to the switch pad. Via size/drill from the design brief.
    169 segments + 15 vias, reloads cleanly in pcbnew. Validated by differencing
    connectivity: with vs without the links closes exactly 15 ratsnest connections
    (31 -> 16 unconnected), one per key. Remaining 16 are deferred MCU/power/USB.
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2026-06-08 feat(router): native arc trace output + pin visual best-practices in roadmap
    Trace-quality track A. geometry.fit_arcs greedily collapses each spline sample
    polyline into native KiCad (arc ...) + (segment ...): at each step it grows both
    a straight chord run and a circular arc (points within 0.05mm tolerance) and
    keeps whichever reaches further, so dead-straight columns stay one segment and
    staggered rows / thumb Béziers become smooth arcs. Emitted via kwrite.curve,
    repointed from kwrite.polyline in the spine and thumb-transition paths.
    Matrix dropped from ~185 straight chords to 26 arcs + 24 segments + 15 vias;
    connectivity unchanged (16 unconnected), file<->pcbnew arc parity exact, no
    deg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
2026-06-08 fix(footprint): correct swapped BAT/RST pads on xiao_ble
    The XIAO underside pads were mislabelled: the 4 inner pads near the USB end
    were assigned to BAT, and the side mid-board pad to RST. Verified against the
    source this footprint was adapted from (GEIGEIGEIST/TOTEM schematic + footprint)
    that it is the reverse: the 4 inner pads are the SWD debug group
    (SWDIO/SWCLK/RESET/GND) and the side pad is the actual battery (BAT) terminal.
    As-was, the keyboard's BATT net (cell -> power switch -> XIAO) soldered onto the
    XIAO's SWD/RESET pins. Now BAT routes to the real battery pad; the 4 debug pads
    are left unconnected as access holes. Affects both halves (shared mcu_params).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
2026-06-08 fix(config): correct mounting-hole + battery positions to match case
    The shift Y-components for the four M2 mounting holes and the battery were
    sign-flipped (computed in Ergogen's y-up frame without accounting for KiCad's
    y-down export), so they landed mirrored -- pushing the battery and the two
    bottom bolts off the board edge instead of onto the case bolt/pocket positions.
    Corrected the five Y-shifts. All six case-aligned parts (4 bolts, battery,
    already-correct MCU + power switch) now land exactly on their phantom_case.scad
    targets. Documented the board<->case transform (case = board + (80, 58.97),
    matrix_inner_home at board (36, -21.70)) in a comment so future placements are
    derivable. B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
2026-06-08 fix(router): make matrix links + thumb area DRC-clean (44 -> 0 copper)
    Three geometry fixes, each verified by re-running KiCad DRC:
    - Matrix links: the straight switch-pad -> diode-pad B.Cu diagonal cut through
    the switch's alignment NPTH and (on thumb columns) was crossed by the column's
    thumb Bezier. Route it as a south detour in the switch local frame (rotated by
    fp_rot), drop the via at the south waypoint in open space, and run the long
    west leg on F.Cu -- leaving only a short B.Cu stub. Kills 13 NPTH clips and
    the topologically-unavoidable single-layer thumb crossings.
    - Rows: offset the spine off the pad line (1.5 -> 2.0mm) so it clears the
    matrix pads even where a row's d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
2026-06-08 fix(footprint): clear silkscreen DRC warnings on power switch + xiao
    - power_switch: the body outline reached the PCB edge (the switch overhangs);
    pull the silk box in to +/-1.4mm so it clears Edge.Cuts.
    - xiao_ble: the "USB" label overlapped the (now unconnected) SWD access holes
    and couldn't fit at the board's 0.8mm min text height between them and the
    edge, so remove it (orientation is clear from the case USB cutout).
    Board is now fully DRC-clean (0 violations).
2026-06-09 fix(config): correctly mirror board_right outline (was ~18mm off)
    The board_right perimeter pre-negated its x-shifts, but Ergogen already flips x
    for a mirror_* anchor -- double-negating pushed the right-half outline ~18mm and
    left the MCU hanging off the board's left edge (6 DRC violations on the bare
    right board). The shifts are now identical to board_left; Ergogen does the flip.
    Verified: right outline now spans x[102.65,219.18], mirroring all component
    centres about x=85 (MCU/battery/switch/mount all agree). Bare-right DRC 6 -> 2.
2026-06-09 docs: update STATE.md resume point (session handoff)
    Left half DRC-clean; right-half outline fixed + placement confirmed correct per
    the non-reversible-mirror intent. Next: re-run right-half routing on the
    corrected board, resolve 2 pinky-pad edge near-misses.
2026-06-09 fix(router): steer matrix-link detour toward diode (mirror-safe)
    The per-key matrix-link via drops 6mm south in the switch local frame; the
    small horizontal lean from fp_rot pointed inboard on the left half but, once
    fp_rot flips sign under mirroring, pointed toward the outer board edge on the
    right -- where the pinky switch pad already sits. That pushed the via and its
    B.Cu/F.Cu stubs over the edge (6 copper_edge_clearance violations).
    The diode is interior on both halves, so orient the lean toward the diode.
    Right-half routing now DRC-clean: 8 -> 2 violations, the 2 remaining being the
    inherent pinky-pad edge near-misses (present on the bare board). Left half
    unchanged at 0.
    Co-Authored-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
2026-06-09 fix(config): 0.7mm outline relief for right-half pinky pads
    S12/S13 keep socket orientation under the mirror, so their pad 2 reached the
    outer board edge (copper_edge_clearance 0.018mm / 0.000mm vs 0.5mm rule). Push
    board_right's outer edge segment outward 0.7mm at the two shared corner points.
    board_right feeds only the right PCB (no case outline depends on it), so the
    relief is local. Right-half DRC now 0 violations (was 2); left unchanged at 0.
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2026-06-09 wip(router): row MCU fan-out (near stack) under --mcu-fanout (step 11)
    route_row_fanout: rows and MCU pads are both F.Cu, so each is a single via-less
    trace. The near pad stack (matrix side) escapes the pad column with a staggered
    turn and runs in to the row's open diode end; the far stack (R2/R3) is boxed
    behind the MCU body and its only margin is occupied by the power switch, so it
    is deferred to the MCU-region router rather than emitted as a colliding trace.
    Near rows nearly clean on the left (R1 clean; R0 grazes one choc body NPTH on
    its deep x19.6 target) but the mirror geometry breaks several on the right --
    confirming the whole fan-out (columns + most rows, both halves) needs a gridd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
2026-06-09 wip(router): gridded A* MCU-region fan-out (step 11, DRC-clean fallback)
    Adds fanout.py: a two-layer occupancy-grid A* router for the GPIO fan-out, plus
    the extraction it needs -- extract.py now emits no-net mechanical drills (choc
    poles) and the Edge.Cuts outline, and pad sizes. Obstacles are rasterised with
    separate trace- and via-clearance inflations; pads block as rects (a disc
    under-covers the wide 2.75x1.8mm MCU pads' corners); the current net's copper is
    carved free so A* seats on a boxed pad and vias to its real exit.
    On the left half this routes 9/9 fan-out nets (ratsnest 13 -> 4 power-only) at 4
    DRC violations (the boxed far row R2). But the paths are grid zigzags, not the
    brief's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
2026-06-11 feat(case): one case for both halves; boards made exact mirror shapes
    - config.yaml: board_left now carries the same two outline reliefs as
    board_right (0.7mm pinky edge, 0.3mm top edge), so the two PCBs are exact
    mirror images (verified: 0.000mm outline reflection deviation; every
    footprint origin mirrors at x_l + x_r = 170 with identical y). Both halves
    re-routed after the rebuild: still 0 DRC violations / 0 unconnected.
    - case/phantom_case.scad: builds BOTH halves (-D right=true mirrors the
    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
    [phantom_case.scad, phantom_case_bottom.scad]
2026-06-11 fix(case): right bottom shell keeps hotswap pocket chirality
    The hotswap sockets do NOT mirror on the right-half PCB (footprint internals
    keep their orientation; verified across all 15 switches: pad1->pad2 vector
    matches the unmirrored local offsets under the half's rotation). The Z-shaped
    socket pocket is chiral, so the right-half bottom shell now mirrors the pocket
    polygon locally, which the global right-build mirror cancels - pocket
    positions and rotations mirror with the layout, pocket shape keeps the
    socket's handedness.
    Verified two ways: cross-sections of the built L/R STLs show mirrored outlines
    with same-chirality pockets, and the original TOTEM BLE case bottoms (separate
    L/R STEPs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
    [phantom_case_bottom.scad]
2026-06-11 fix(pcb): diodes centred in Choc LED cutouts; GND pours with MCU keepout
    - config.yaml: diode shift -5.95 -> -4.70. The Choc v1 LED body cutout spans
    y 3.075..6.325 (centre 4.70; verified against the ceoloide choc footprint
    and the Rufous ChocSimpleDiode which integrates its diode at exactly
    (+/-1.65, 4.7)). The old -5.95 reused the contact-row offset and left the
    diode body 1.25mm south of centre, fouling the switch housing wall.
    - cli.py: MATRIX_DETOUR 6.0 -> 4.75 so the matrix via->diode-pad-1 leg keeps
    its original angle past the diode's pad 2; river.py waypoint retunes for
    the moved row line (left R0 channel now north of the bottom-row poles,
    clear of the relocated matrix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
    [phantom_case.scad, phantom_case_bottom.scad]
2026-06-11 fix(case): battery pocket minimal growth (wall 40.25, was over-grown to 39.5)
    The pad pair needs an 8.25mm well (8.5mm copper span less end margins);
    moving the pads can't fix it (east = solder under the cell, west = out the
    wall). +0.75mm keeps 1.15mm of material to the BL bolt shaft hole, which the
    previous +1.5mm growth had thinned to 0.4mm.
    [phantom_case.scad]
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2026-06-12 refactor: rename to Eidolon; clean repo structure
    - Rename keyboard from Phantom to Eidolon throughout (config, SCAD, comments)
    - Reorganise: pcb/ (ergogen source + footprints + routed KiCad + gerbers),
    case/ (SCAD files + stl/ with pre-generated STLs), images/ (PCB + case renders)
    - Remove router code (moved to phantom-router repo), autorouter-prompt.md,
    and reference STEP file
    - Add routed eidolon_left/right.kicad_pcb and gerber zips to pcb/
    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
    [eidolon_case.scad, eidolon_case_bottom.scad, eidolon_case_bottom_left.stl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]
2026-06-12 fix(readme): replace case bottoms image with proper per-half renders
2026-06-12 docs(readme): tighten acknowledgements — drop pogo-pin description, credit TOTEM for diode placement
2026-06-12 fix(readme): diode-in-LED-cutout credit belongs to Rufous, not TOTEM
2026-06-12 fix(readme): TOTEM reference is the STEP file only, not silkscreen
